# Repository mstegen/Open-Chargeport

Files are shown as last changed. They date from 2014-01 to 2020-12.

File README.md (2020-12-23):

Open ChargePort
===============

What is it?
As the name suggests, it's a transmitter that will open the charge port of a Model S.

When I received my EU spec model S, i charged a few times with the cable Tesla supplies with the car.
The button to open the Charge port door, really is a nice feature.
As there is no such thing on a standard Type 2 charge cable, i now have to open the car door, touch the battery icon, and select open charge port. Not very convenient.

Therefore i wanted to make my own transmitter that opens the chargeport.

Credits to Banahogg who documented his attempts to analyze the RF data here
which helped me finish this project in a few days.

The components needed:

I used a 433 Mhz module connected to a PIC microcontroller. (US model S, requires a 315Mhz module)
Only a few other components are required.

1x PIC12F1822 or PIC10F200 microcontroller 
1x TX-SAW MID/3V
1x Lithium cell, 3V
2x 100nf capacitor
1x 10uf capacitor
1x pushbutton
 
Please note that the PCB layout in /eagle was designed for the PIC10F200 microcontroller.

=======================================================================================

There is now a new version, based on the same chip Tesla uses in it's Charging Cable.

The chip is a Silabs Si4010, only one external component (capacitor) is required.
I converted the Tesla specific bitstream for use with this microcontroller. 
As Silabs also provided a PCB layout file for 5 buttons, but only one button is needed, these files were modified.
The PCB layout fit's the Polycase FB-20 keyfob housing.

All files for this version can be found in the /Si4010 folder.

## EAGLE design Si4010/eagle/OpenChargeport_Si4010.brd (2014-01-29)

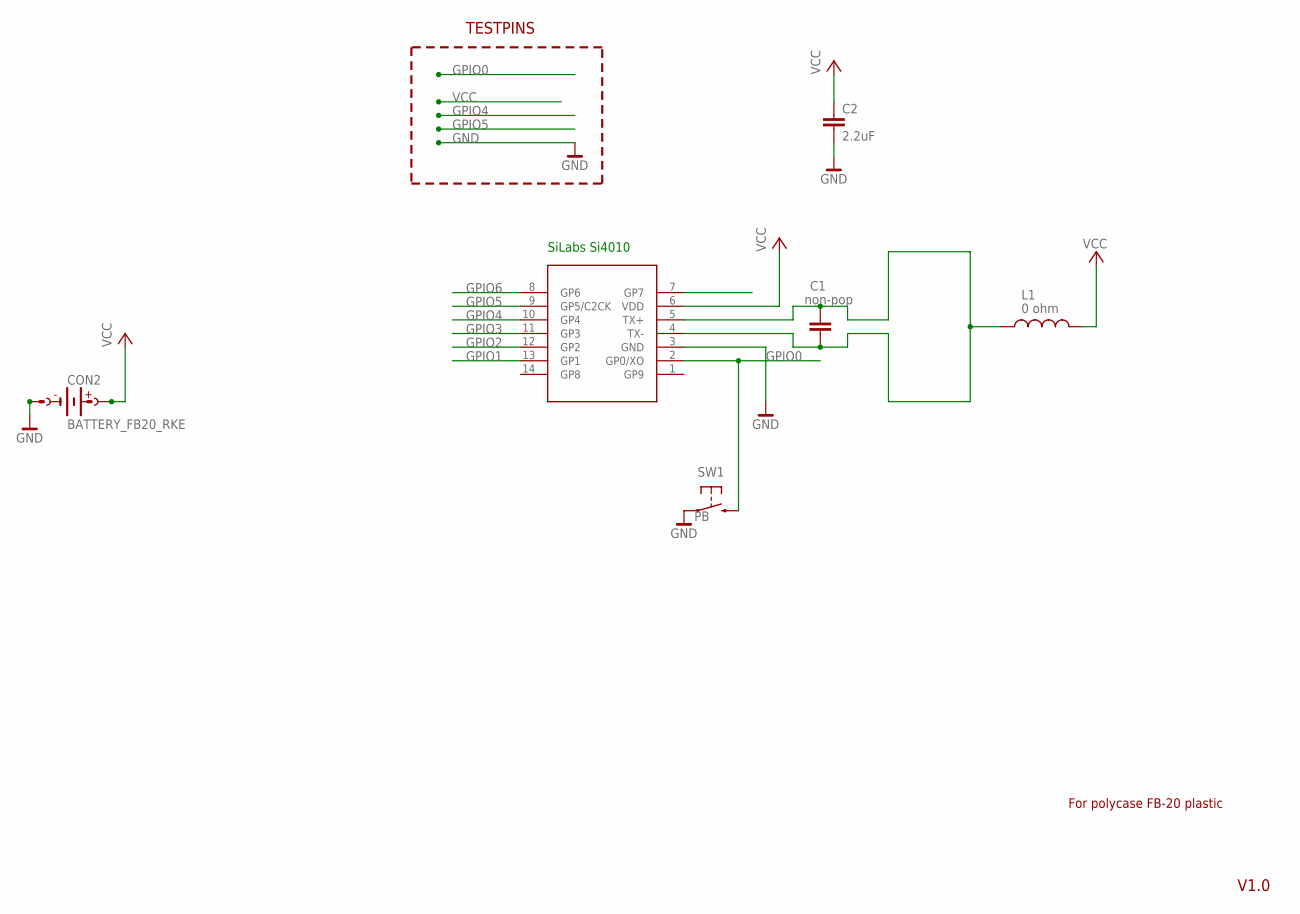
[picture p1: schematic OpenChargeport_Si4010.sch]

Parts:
C1: non-pop; C0603K
C2: 2.2uF; C0805K
CON2: BATTERY_FB20_RKE; BATTERY_HOLDER_CR2032F_RKE_FB20
IC1: SI4010; SOIC-14
L1: 0 ohm; L0402
SW1: PB; PUSHB_PILL

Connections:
ANT: C1.1, C1.2, IC1.4 (TX-), IC1.5 (TX+), L1.1
GND: C2.2, CON2.MINUS (NEG), CON2.MINUS1 (NEG1), IC1.3 (GND), SW1.P$1 (1)
GPIO0: IC1.2 (GP0/XO), SW1.P$2 (2)
GPIO1: IC1.13 (GP1)
GPIO2: IC1.12 (GP2)
GPIO3: IC1.11 (GP3)
GPIO4: IC1.10 (GP4)
GPIO5: IC1.9 (GP5/C2CK)
GPIO6: IC1.8 (GP6)
VCC: C2.1, CON2.PLUS1 (POS), CON2.PLUS2 (POS1), IC1.6 (VDD), L1.2

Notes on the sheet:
TESTPINS
For polycase FB-20 plastic
V1.0
SiLabs Si4010

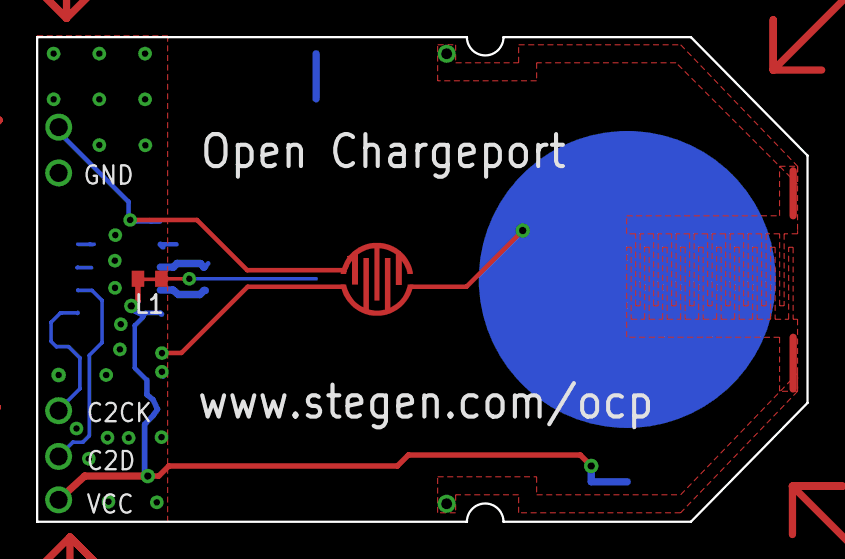
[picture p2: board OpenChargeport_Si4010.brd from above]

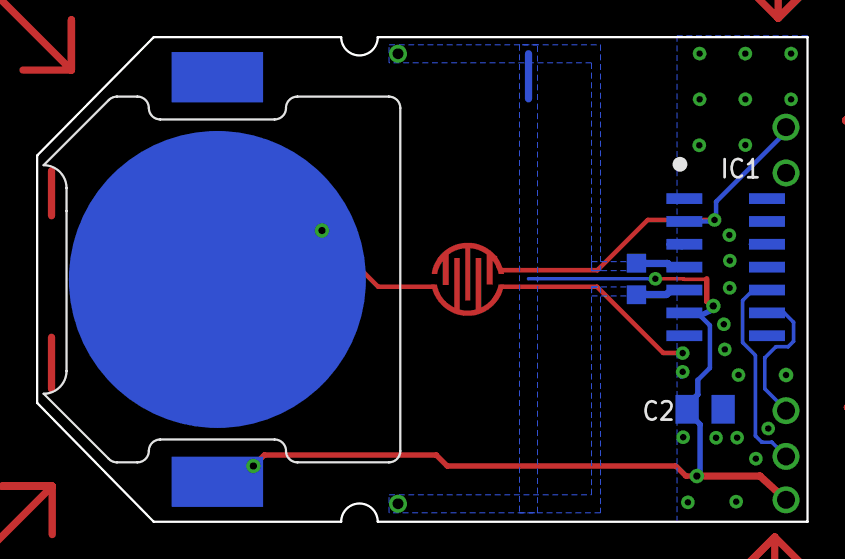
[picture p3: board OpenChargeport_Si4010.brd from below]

Board: 2 copper layers, 42.8 x 26.9 mm, 6 parts (4 on the bottom side), 4 nets.

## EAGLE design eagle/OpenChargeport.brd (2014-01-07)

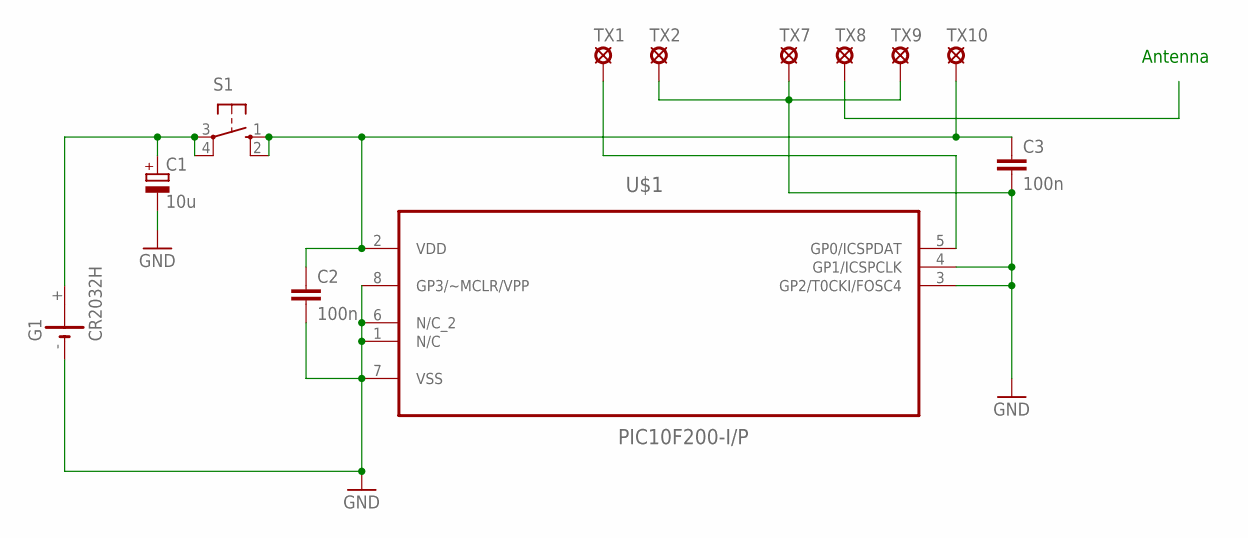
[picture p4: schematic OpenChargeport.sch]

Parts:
C1: 10u; E2,5-5
C2, C3: 100n; C025-025X050
G1: CR2032H
S1: 10-XX; B3F-10XX
TX1, TX2, TX7, TX8, TX9, TX10: LSP10
U$1: PIC10F200-I/P; DIP254P762X533-8

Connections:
GND: C1.-, C2.2, C3.2, G1.-, TX2.MP, TX7.MP, TX9.MP, U$1.1 (N/C), U$1.3 (GP2/T0CKI/FOSC4), U$1.4 (GP1/ICSPCLK), U$1.6 (N/C_2), U$1.7 (VSS), U$1.8 (GP3/~MCLR/VPP)
unnamed: C1.+, G1.+, S1.3, S1.4 (P1)
unnamed: C2.1, C3.1, S1.1 (S), S1.2 (S1), TX10.MP, U$1.2 (VDD)
unnamed: TX1.MP, U$1.5 (GP0/ICSPDAT)

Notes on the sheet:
Antenna

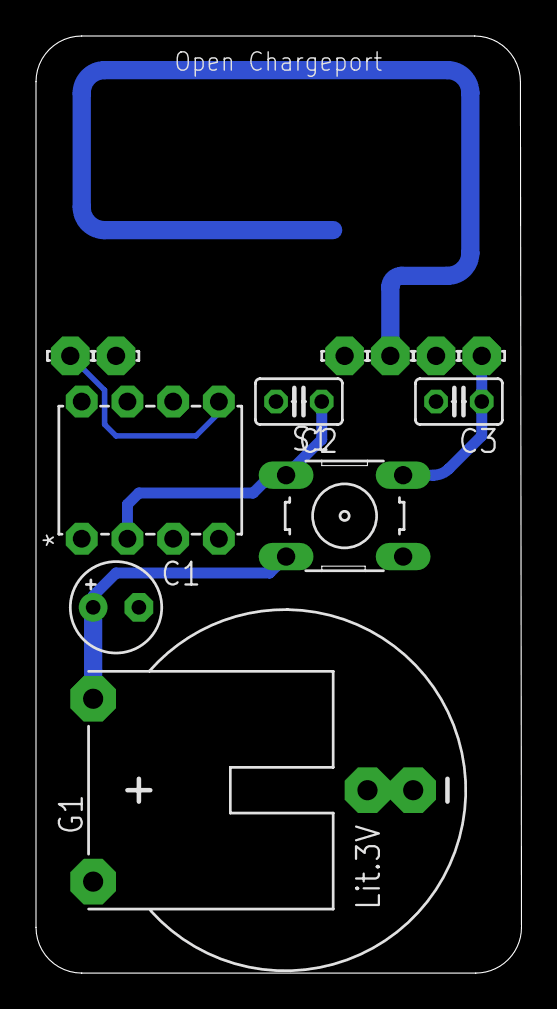
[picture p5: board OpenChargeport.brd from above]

Board: 2 copper layers, 27.0 x 52.1 mm, 12 parts (0 on the bottom side), 4 nets.

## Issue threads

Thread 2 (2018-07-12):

how to burn the files to SI4010?

fenrei, 2018-07-12:
inside source code folder of the  Si4010 folder, there is no HEX file to use, only a .c and .h file, please tell me how can i use with these 2 files, thanks!

mstegen, 2018-07-12:
It's been a while, but you'll need to install Silicon Laboratories wireless development suite, and install the KEIL compiler.
Then also install the example files for the SI4010, see here:
https://www.silabs.com/documents/public/application-notes/AN690.pdf
https://www.silabs.com/documents/public/user-guides/Si4010-DK.pdf

It helps if you own one of the dev kit's as the software is included.
I bought the 4010-DKKF-434 kit, but i noticed it has been replaced by (i think) the 4010-KFOBDEV-434.

Overwrite the installed example (keyfob_demo) with the two files from this repository.
You should then be able to compile the keyfob_demo example, generating the Open Chargeport hexfile.

Be careful, as you can only burn the Si4010 IC's once!, (you can however upload the code to RAM and develop from there)

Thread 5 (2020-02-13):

Does the PIC and Si4010 code generate exactly the same signal?

nicholas-gh, 2020-02-13:
I've determined that https://github.com/mstegen/Open-Chargeport/blob/4fdffded66910fe04250e5dc19f3d89ede9bd17c/Si4010/source/keyfob_demo_main.c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 is the same data as https://teslamotorsclub.com/tmc/posts/2383825/ - after I spotted the [note about LSB](https://github.com/mstegen/Open-Chargeport/blob/4fdffded66910fe04250e5dc19f3d89ede9bd17c/Si4010/source/keyfob_demo_main.c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). The Si4010 code is 'ready to send', so manchester encoding, preamble, message-repeats markers are all already in it; and since the 'message-repeats' marker (100?) isn't a full byte I see how the repeated data actually doesn't look repeated in the Si4010 code.

The data at https://github.com/mstegen/Open-Chargeport/blob/4fdffded66910fe04250e5dc19f3d89ede9bd17c/sourcecode/OpenChargeport_10F200.asm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 is almost the same; but the last few bytes of the repeated message seems to differ.

I think the PIC code generates either

```
010101100101100110010110011001100110011001011010011010010110101001010110100110100110010101011010 100101
```
or potentially (if I'm confused how (MC_TX3)[https://github.com/mstegen/Open-Chargeport/blob/4fdffded66910fe04250e5dc19f3d89ede9bd17c/sourcecode/OpenChargeport_10F200.asm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] works)
```
010101100101100110010110011001100110011001011010011010010110101001010110100110100110010101011010 100
```

and the Si4010 and 'rpitx' examples generate

```
0101011001011001100101100110011001100110010110100110100101101010010101101001101001100101010110100101 100
```

I assume all three of these examples work, and the Tesla port doesn't notice the small variation?

If it works (and I assume it must do since it's here), then the PIC code has the most concise representation of the Tesla button code I've come across so far.

nicholas-gh, 2020-02-13:
Here's my python playaround  to try compare the three examples:
```python
#!/usr/bin/python

# sources
# https://teslamotorsclub.com/tmc/posts/2383825/
# https://github.com/mstegen/Open-Chargeport/blob/master/Si4010/source/keyfob_demo_main.c

thenoone_preamble = "111111111111"
thenoone_data = "00010010100101010101001101100111000110110100001100"
thenoone_rec_split = "100" # not manchester?

Si4010 = [0x55, 0x55, 0x55, 0x51, 0xd3, 0x4c, 0x33, 0x33, 0xd3, 0xb2, 0xb4, 0x52, 0xcb, 0x32, 0xd5, 0xd2, 0xA8, 0x69, 0xa6, 0x99, 0x99, 0x69, 0x59, 0x5a, 0xa9, 0x65, 0x99, 0x6a, 0x69, 0xd4, 0x34, 0xd3, 0xcc, 0xcc, 0xb4, 0x2c, 0xad, 0xd4, 0xb2, 0x4c, 0xb5, 0x34]

pic_preamble = "10"*13 + "0" # 0 is an extra 400us delay after the preamble that's in the code, not in the data
pic = [0x12, 0x95, 0x53, 0x67, 0x1B, 0x43]
pic_3 = 0x20

def manchester(data):
    return "".join(["10" if bit == "1" else "01" for bit in data])
thenoone_symbols = thenoone_rec_split.join([manchester(thenoone_preamble)] + [manchester(thenoone_data)]*3)

print "noone ", [int(thenoone_symbols[b:b+8][::-1], 2) for b in range(0, len(thenoone_symbols), 8)]
print "Si4010", Si4010

pic_symbols = pic_preamble + ("".join([manchester(format(byte, '08b')) for byte in pic]) + manchester(format(pic_3, '03b')))*3
print "pic   ", [int(pic_symbols[b:b+8][::-1], 2) for b in range(0, len(pic_symbols), 8)]

```

and the output is

```
noone  [85, 85, 85, 81, 211, 76, 51, 51, 211, 178, 180, 82, 203, 50, 213, 210, 168, 105, 166, 153, 153, 105, 89, 90, 169, 101, 153, 106, 105, 212, 52, 211, 204, 204, 180, 44, 173, 212, 178, 76, 181, 20]
Si4010 [85, 85, 85, 81, 211, 76, 51, 51, 211, 178, 180, 82, 203, 50, 213, 210, 168, 105, 166, 153, 153, 105, 89, 90, 169, 101, 153, 106, 105, 212, 52, 211, 204, 204, 180, 44, 173, 212, 178, 76, 181, 52]
pic    [85, 85, 85, 81, 211, 76, 51, 51, 211, 178, 180, 82, 203, 50, 213, 74, 85, 53, 205, 52, 51, 51, 45, 75, 43, 181, 44, 83, 173, 84, 85, 211, 76, 51, 51, 211, 178, 180, 82, 203, 50, 213, 74, 85]
```

So the Si4010 and TheNoOne's code varies only at the very end; but I don't understand the Pic code well enough to see if/why its "3 bit" "frame delimiter" is the same result as the other two.

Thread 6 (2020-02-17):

debug / run

FlexyZ-xx, 2020-02-17:
Hi

I know this project is an old one. I just got the si4010-kfobdev-434 devkit and got all the software running - was a pain to find it all

Anyway from Silabs IDE I can connect to the "4010-DKPB434-BM" and download code, but how do I run the code with out being connected to the toolstick/debugger?

Is it correct that I can only burn/flash ones - also on the "4010-DKPB434-BM"?

I hope you can help me :)

Thanks
Felix

mstegen, 2020-02-17:
For programming i used Si4010_NVM_Burn_CL.exe called by a batch file. I found it programmed the fastest.
Not sure anymore where i got that from. It's in a folder called Si4010_NvmProgUtil
Yes the Si4010 IC's are one time programmable only, but as you noticed you can debug/load the program in RAM to test if everything works.

FlexyZ-xx, 2020-02-17:
Thanks for your reply :) - I tried to change the LED to constantly on, but no LED - there is a red LED with activity when uploading code og multi-step

When I press F5/RUN can I remove 4010-DKPB434-BM from the Toolstick and should it keep running? - it has a battery on the back side. Or do I have to test while connected to my computer?

btw. Will this https://www.telstore.it/en/650201131g.html work for the PIC project?

Felix

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

FlexyZ-xx, 2020-02-17:
Hey

Maybe I did not create the project correct in Silabs IDE. I just added your files and the 4010 include files.

But when I "Build Male/Project" I get a lot of *** WARNING L1: UNRESOLVED EXTERNAL SYMBOL
, so I guess I need to link with a library or?

Thanks again
Felix

FlexyZ-xx, 2020-02-17:
Got a little closer by adding the license to KEIL - tried to replace the .c and .h on the "keyfob_demo_2" example folder, but don't seem to work - does the screendump look correct? - or could you send me your original project, so I get all the options correct?

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

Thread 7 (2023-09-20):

Is code change required if we use Si4010 10-pin variant?

mgsanava, 2023-09-20:
This is not an issue maybe.
I replicated the Si4010 based circuit and dumped the hex code into IC. I'm using 10-pin variant of Si4010.

(Download sample codes from Si4010 page -> duplicated keyfob_demo_2 project -> deleted the actual usr_src files -> added your source files -> compiled successfully -> hex generated -> downloaded hex successfully using Silabs IDE)

Now when I press the switch, I couldn't see any signal on the TXM TPM pins. Attached schematic also.

Do I need to change something in code? All I could see was TXM TPM pin numbers were changed.

I posted this on Tesla club also but was approved yet and this is urgent. Hence posting here again. Any help is appreciated. Thanks.

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

mstegen, 2023-09-21:
I don't think the variant of the IC matters. But please check the sourcecode, if you want to test the code, you can run the program from RAM, to do so you will have to comment out some lines. The chips can be flashed only once, so if you flashed your IC, you will have to unsolder it, and solder in a new one.

Looking at your schematic, C2 should not be 100nf, in my schematic it's unused., as this is the output of the transmitter, the 100nf capacitor will absorb the RF signal.

mgsanava, 2023-09-22:
Thank you for the reply.
> The chips can be flashed only once
I got lost there. I burned the chip 3 times already but it never said download failed.
Every time code was downloaded successfully which I could see in IDE log window. Definitely something is wrong?
I will change the chip anyway.

I checked the source code but I do not see anything related to RAM. I will dig deeper and it would be great if you can provide any leads on this topic.

I removed the C2 as suggested.

mgsanava, 2023-09-25:
@mstegen
Can you please comment?

mstegen, 2023-09-26:
It has been 10 years ago since i last looked at the code, i don't have the IDE installed anymore on my PC, but i remembered that you could run the software from RAM, and not program it to flash.

Please search the documentation for this. Also this is the line that you need to comment out if you want to debug it:

https://github.com/mstegen/Open-Chargeport/blob/331fc6fb402cc5cf49b122092cd722234c0e0293/Si4010/source/keyfob_demo_main.c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

mgsanava, 2023-09-26:
I'll look into documentation further.
Thanks for the help!

mgsanava, 2023-09-29:
This is just a note about Si4010 Flashing for future readers including myself:

_**Courtesy: Silabs Community**_
Si4010 stores the user code in OTP memory (called NVM in documentation). Programming NVM requires 6.5V programming voltage and Silabs NVM programming utility SW, cannot be done from IDE. During boot, user code is loaded from NVM to RAM, and runs from RAM.

IDE loads the code directly to RAM for debugging, that's why you can do it multiple times.

RAM content is lost in shutdown state.

No code change needed for 10-pin variant, if you do not use the nonexistent GPIOs.

See further details in [Si4010 datasheet](https://www.silabs.com/documents/public/data-sheets/Si4010.pdf) and [AN370: Si4010 Software Programming Guide](https://www.silabs.com/documents/public/application-notes/AN370.pdf)

mgsanava, 2023-10-11:
Hi @mstegen
just wanted a help from you. do you still have the waveforms data on how they look on an oscilloscope?
i tried the setup and ended up with some signal but i'm quite sure they are not correct.
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

mstegen, 2023-10-12:
No i do not have the waveform, but you can record it yourself with a 433 mhz receiver, and a tesla wall connector plug.
Please note that in the USA, the frequency is not 433 Mhz but 315Mhz if i remember correctly. That might be the reason it does not work for you.
You can set the TX frequency in the sourcecode. The antenna is not tuned for 433 Mhz, but it should still work on 315Mhz. (i verified that at the time)

Closed 2023-09-26.

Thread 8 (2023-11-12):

What is the purpose of L1?

markusdd, 2023-11-12:
L1 (which is only a 0 Ohm resistor as it seems) apparently supplies VCC to the antenna and is populated: why?

Can you maybe point to the datasheet where this is used? Or is this supposed to be a Ferrite Bead?

Also: wouldn't it make sense to try to fit it on the bottom layer as well so the PCB becomes easier to manufacture? Because currently it would require 2-sided assembly.

mstegen, 2023-11-13:
It was a hack to connect the two busses (VCC and ANT) together

markusdd, 2023-11-13:
I thought so.
I imported the board files into KiCAD and noticed that otherwise DRC will go crazy on you^^

Is there a reason why the whole antenna is put under VDD? Is that recommended by SiLabs?

mstegen, 2023-11-13:
I used their reference PCB design, and deleted the other 4 buttons, but kept everything else the same.

markusdd, 2023-11-13:
Interesting stuff, need to read up on why they do that, never have seen that before.

Thanks for your insights!

Closed 2023-11-13.

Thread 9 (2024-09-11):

Is Hex file available for Si4010 version (with 315MHz frequency support)?

mgsanava, 2024-09-11:
Hi @mstegen

I was able to compile the code available in your repo but not sure if it is working or not because I was not able to identify any output signal after flashing the code (tried on both RAM and OTP memories). I am checking in an oscilloscope, and I don't have the facilities to test with an actual car because I'm in a different country.

I could see [here](https://github.com/mstegen/Open-Chargeport/blob/331fc6fb402cc5cf49b122092cd722234c0e0293/Si4010/source/keyfob_demo.h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) that frequency you assigned is 433MHz for EU region. For which value assigned was _433920000_. Is there any specific reason why it is not _433000000_? Can I just use _315000000_ for 315MHz?

My schematic and board are completely identical to the one in the repo. Is it enough to just modify the [`fOperatingFrequency`](https://github.com/mstegen/OpenChargeport/blob/331fc6fb402cc5cf49b122092cd722234c0e0293/Si4010/source/keyfob_demo.h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) and flash? Or do I need to comment out any lines in the code?

Schematic:
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
Please let me know if PCB layout is required.

Your help is highly appreciated. Thanks!

mgsanava, 2024-09-12:
PCB:

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

mstegen, 2024-09-12:
The reason for the 433,920 Mhz frequency is because that exact frequency is used on all transmitters in the EU, it's free to use.
In the USA it's 315 Mhz, not sure about the exact frequency.
I once sent a OpenChargeport key fob to the USA to test, and it worked fine, even with the default antenna design.

You can test your transmitter by using a 315Mhz receiver module connected to your oscilloscope.

mgsanava, 2024-09-13:
Thanks @mstegen
My receiver is: XY-MK-5V (315MHz) version for testing where I probe DATA pin for signal capture.
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

I am not sure if DATA pin signal frequency is downscaled or not because I have an oscilloscope of 100MHz and 1Gs read specification. As far as I know, frequencies higher than 100MHz bandwidth will not be captured by scope correctly.
I did not find further information about this DATA pin, but I see people using Arduinos to interpret the signal on DATA pin using serial monitor.

Is there a better way to interpret the receiving signal?

mstegen, 2024-09-13:
If you follow the original thread on teslamotorclubforum you can see what you should expect to see on your scope screen.
The bandwidth of your scope is fine.
As this project was done a long time ago i don't remember any more details, sorry.

mgsanava, 2024-09-17:
It's ok, thanks.
One last question - if I want to try this out in another microcontroller, I just need to relay the exact 42-byte data sequence in the [vPacketAssemble()](https://github.com/mstegen/Open-Chargeport/blob/331fc6fb402cc5cf49b122092cd722234c0e0293/Si4010/source/keyfob_demo_main.c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) function, right?

mstegen, 2024-09-17:
No, that depends on how the data is transmitted, as you can see in the pic code here:
https://github.com/mstegen/Open-Chargeport/blob/master/sourcecode/OpenChargeport.asm#L203

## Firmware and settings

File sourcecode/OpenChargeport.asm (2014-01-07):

;******************************************************************************
;   Open Chargeport                         						          *
;   For use with Tesla Model S                                                *
;******************************************************************************
;                                                                             *
;    Filename:     OpenChargeport.asm                                         *
;    Date:         4-9-13                                                    *
;    File Version: 1.00                                                       *
;                                                                             *
;    Author:       M. Stegen                                                  *
;    Company:      Stegen Electronics                                         *
;                                                                             *
;                                                                             *
;******************************************************************************
;                                                                             *
;    *
;    *
;	 
;																			  *
;******************************************************************************
;                                                                             *
;    Revision History:                                                        *
;	 1.00 		initial release												  *
;																			  *
;******************************************************************************
;
;
;
;	       +----_----+
;	 VDD --| 1     8 |-- GND 
;	 NC  --| 2     7 |-- TX Out
;	 NC  --| 3     6 |-- NC
;	 NC  --| 4     5 |-- NC
;	       +---------+
;
;
;*****************************************************************************



	list		p=12F1822      ; list directive to define processor
	#include	<p12F1822.inc> ; processor specific variable definitions

;------------------------------------------------------------------------------
;
; CONFIGURATION WORD SETUP
;
; The 'CONFIG' directive is used to embed the configuration word within the 
; .asm file. The lables following the directive are located in the respective 
; .inc file.  See the data sheet for additional information on configuration 
; word settings.
;
;------------------------------------------------------------------------------    

    __CONFIG _CONFIG1, _FOSC_INTOSC & _WDTE_OFF & _PWRTE_ON & _MCLRE_OFF & _CP_ON & _CPD_ON& _BOREN_OFF & _CLKOUTEN_OFF & _IESO_OFF & _FCMEN_OFF
    __CONFIG _CONFIG2, _WRT_OFF & _PLLEN_OFF & _STVREN_OFF & _BORV_19 & _LVP_OFF



;------------------------------------------------------------------------------
; VARIABLE DEFINITIONS
;
; Available Data Memory divided into Bank 0-15.  Each Bank may contain 
; Special Function Registers, General Purpose Registers, and Access RAM 
;
;------------------------------------------------------------------------------

; RAM-Variables


Mcount      EQU    	0x71
Count		EQU		0x72
Serdata		EQU		0x73

TX			EQU		0		; pin 7	TX output

;------------------------------------------------------------------------------
; RESET VECTOR
;------------------------------------------------------------------------------

    ORG     0x0000            ; processor reset vector

	goto    INIT              ; When using debug header, first inst.
                              ; may be passed over by ICD2.  

;-------------------------------------------------------------------------
; Send 3 bits (in W) (MSB)

MC_TX3
		movwf	Serdata
		MOVLW 	3
		MOVWF 	Count			; 3 BITS TO send
		goto	MC_TXLOOP

;-------------------------------------------------------------------------
; Send one byte (in W)
MC_TX
		movwf	Serdata
		MOVLW 	8
		MOVWF 	Count			; 8 BITS TO send
		
MC_TXLOOP
		CLRF	TMR0

		BTFSS	Serdata,7		; check MSB
		BCF		PORTA,TX		; Signal LOW 	=> 01
		BTFSC	Serdata,7		; check MSB
		BSF		PORTA,TX		; Signal HIGH 	=> 10
MC1_400us
		MOVF	TMR0,W
		XORLW	.25				; 0.000016 * 25= 400 uS
		BTFSS	STATUS,Z
		GOTO	MC1_400us

		BTFSC	Serdata,7		; check MSB
		BCF		PORTA,TX		; Signal LOW	=> 01
		BTFSS	Serdata,7		; check MSB
		BSF		PORTA,TX		; Signal HIGH	=> 10

MC2_400us
		MOVF	TMR0,W
		XORLW	.50				; 0.000016 * 50= 800 uS total
		BTFSS	STATUS,Z
		GOTO	MC2_400us

		RLF		Serdata,F
		decfsz	Count,F
		goto	MC_TXLOOP	
		return


;------------------------------------------------------------------------------
;
SEND_SYNC
		BANKSEL PORTA

		movlw	.13
		movwf	Count
sync_loop
		CLRF	TMR0
		BSF		PORTA,TX		; High
high_400
		MOVF	TMR0,W
		XORLW	.25				; 0.000016 * 25= 400us
		BTFSS	STATUS,Z
		GOTO	high_400

		BCF		PORTA,TX		; Low
low_400
		MOVF	TMR0,W
		XORLW	.50				; 0.000016 * 50= 800us
		BTFSS	STATUS,Z
		GOTO	low_400
		decfsz	Count,F			; repeat
		goto	sync_loop
		return	

;------------------------------------------------------------------------------
;
delay400us
		CLRF	TMR0
dly400us
		MOVF	TMR0,W
		XORLW	.25				; 0.000016 * 25= 400 uS
		BTFSS	STATUS,Z
		GOTO	dly400us
		return

delay25ms
		movlw	.62
		movwf	Count
dly25ms		
		call	delay400us
		decfsz	Count,F
		goto	dly25ms
		return
	

;------------------------------------------------------------------------------
; INITIALIZE all REGISTERS
;------------------------------------------------------------------------------

INIT	
		BANKSEL OPTION_REG
		movlw	B'11000110'
		movwf	OPTION_REG		; prescaler 1:128, Weak pull-ups disabled
								; same bank
		movlw	b'11110000'		
		movwf	OSCCON			; setup 32Mhz internal oscillator

		BANKSEL PORTA 
		CLRF 	PORTA 			; Init PORTA
		BANKSEL LATA 			; Data Latch
		CLRF 	LATA 
		BANKSEL ANSELA 
		CLRF 	ANSELA 			; digital I/O
		BANKSEL TRISA 		
		MOVLW 	B'00111110' 	; set pin 7 as output (TX)
		MOVWF 	TRISA 			; the rest as input



MAIN
		call	SEND_SYNC		; send 13 sync bits
		movlw	.3
		movwf	Mcount
Mloop
		call	delay400us
		movlw	0x12			
		call	MC_TX
		movlw	0x95			
		call	MC_TX
		movlw	0x53			
		call	MC_TX
		movlw	0x67			
		call	MC_TX
		movlw	0x1B			
		call	MC_TX
		movlw	0x43			
		call	MC_TX
		movlw	0x20			
		call	MC_TX3
		decfsz	Mcount,F
		goto	Mloop

		call	delay25ms

		goto 	MAIN			; loop forever
    


    END

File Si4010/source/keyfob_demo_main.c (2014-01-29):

/*------------------------------------------------------------------------------
 *                          Silicon Laboratories, Inc.
 *                           http://www.silabs.com
 *                               Copyright 2010
 *------------------------------------------------------------------------------
 *
 *    FILE:       keyfob_demo_main.c
 *    TARGET:     Si4010
 *    TOOLCHAIN:  Keil
 *    RELEASE:    1.1 ; ROM version 02.00
 *    AUTHOR:     Miklos Lukacs, 
 *                modified by Michael Stegen for use as Open Chargeport
 *    DATE:       October 07, 2013
 *
 *------------------------------------------------------------------------------
 *
 *    DESCRIPTION:
 *      This file contains the main function for the Keil toolchain
 *      sample keyfob_demo project.
 *
 *      BL51 linker directives for building this application:
 *
 *      BL51: PL(68) PW(78) IXREF RS(256)
 *            CODE (0x0-0x08FF)
 *            DATA (0x40)
 *            IDATA (0x80)
 *            XDATA (0x0900-0x107F)
 *            STACK (?STACK(0x8A))
 *
 *------------------------------------------------------------------------------
 *
 *    INCLUDES:
 */
#include <stdlib.h>
#include "si4010.h"
#include "si4010_api_rom.h"

/* Demo header */
#include "keyfob_demo.h"

/*------------------------------------------------------------------------------
 *
 *    FUNCTION DESCRIPTION:
 *      This function tunes the si4010 for transmission and transmits frames.
 *      It consists of two fundamental phases, setup and the transmission loop.
 *
 *      Setup Phase:
 *        The Setup Phase calls all setup function for the need API modules.
 *        These functions are to be called once per boot of the chip.
 *          vSys_Setup
 *          vPa_Setup
 *          vOds_Setup
 *          vStl_EncodeSetup
 *          vFCast_Setup
 *
 *      Transmission Loop Phase:
 *        The Transmission Loop Phase is a loop which transmits the proper frame
 *		  once a button is pushed. Frequency casting, FSK adjustment
 *        and PA tuning are all performed between each transmission.
 *
 *------------------------------------------------------------------------------
 */
void main(void)
{
/*------------------------------------------------------------------------------
 *    SETUP PHASE
 *------------------------------------------------------------------------------
 */
//Set DMD interrupt to high priority,
// any other interrupts have to stay low priority
  PDMD=1;

// Parameters Initialization. 
  vAppInitial();


// Call the system setup. This just for initialization.
// Argument of 1 just configures the SYS module such that the
// bandgap can be turned off if needed.
  vSys_Setup( 1 );

// Setup the bandgap for working with the temperature sensor here 
  vSys_BandGapLdo( 1 );
 
// Setup the BSR 
  vBsr_Setup( &rBsrSetup );

// Setup the RTC to tick every 5ms and clear it. Keep it disabled. 
  RTC_CTRL = (0x07 << B_RTC_DIV) | M_RTC_CLR;

// Enable the RTC 
  RTC_CTRL |= M_RTC_ENA;

// Enable the RTC interrupt and global interrupt enable 
  ERTC = 1;
  EA = 1;

// Setup the PA 
  vPa_Setup( &rPaSetup );

// ODS setup 
  vOds_Setup( &rOdsSetup );

// Setup the STL encoding to NoneNrz code. we
// leave the pointer at NULL. 
//  vStl_EncodeSetup( bEnc_Manchester_c, NULL );
  vStl_EncodeSetup(   bEnc_NoneNrz_c, NULL );


// Setup frequency casting .. needed to be called once per boot 
  vFCast_Setup();



/*------------------------------------------------------------------------------
 *    TRANSMISSION LOOP PHASE
 *------------------------------------------------------------------------------
 */

 // Application loop, including push button state analyzation and transmission.
  while(1)
  {
    // Buttons analyzation and update task flag. 
    vButtonCheck();

    if (bAp_ButtonState)
    {
      // Set frame size and frame header pointer 
      vPacketAssemble();
	  if (lPayLoad)
	  {
      // Start to transmit
      vRtl_RepeatTxLoop();
      }
    }
    else if( (lSys_GetMasterTime() >> 5) > bMaxWaitForPush_c )
    {
      // Shutdown if timeout, currently after about 1.6s,
      // For debugging with IDE, comment it out since it does not support boot.
      vSys_Shutdown();
    }
  }
}


/*------------------------------------------------------------------------------
 *
 *    FUNCTION DESCRIPTION:
 *      Initialization of Application parameters. 
 *
 *------------------------------------------------------------------------------
 */
 void vAppInitial(void)
{
// Disable the Matrix and Roff modes on GPIO[3:1] 
  PORT_CTRL &= ~(M_PORT_MATRIX | M_PORT_ROFF | M_PORT_STROBE);
  PORT_CTRL |=  M_PORT_STROBE;
  PORT_CTRL &= (~M_PORT_STROBE);

// Turn LED control off 
  GPIO_LED = 0;
// Set LED intensity .. acceptable values are 0 (off) or 1, 2, and 3 
  vSys_LedIntensity( 0 );

  // Initial debouce time. 
  bIsr_DebounceCount = 0;
  // debounce time definition, the unit is defined by the RTC interrupt time
  //(5ms in the demo).It means that the interval between calls to the
  // vBsr_Service() function is 5*8=40ms.
  // BSR parameters initialization 
  rBsrSetup.bButtonMask = 0x1F;	// GPIO0 only
  rBsrSetup.pbPtsReserveHead = abBsrPtsPlaceHolder;
  rBsrSetup.bPtsSize = 10;
  rBsrSetup.bPushQualThresh = 3;

// Setup the PA.
// fAlpha and fBeta has to be set based on antenna configuration.
// Chose a PA level and nominal cap. Both values come from
// the calculation spreadsheet. 
  rPaSetup.fAlpha      = 0.0;
  rPaSetup.fBeta       = 0.3593;
  rPaSetup.bLevel      = 0;
  rPaSetup.wNominalCap = 10;
  rPaSetup.bMaxDrv     = 0;

 // Setup the ODS 
  rOdsSetup.bModulationType = bRke_OokMod_c; // Use OOK 
//  rOdsSetup.bModulationType = bRke_FskMod_c; // Use FSK 
  rOdsSetup.bClkDiv         = 5;
  rOdsSetup.bEdgeRate       = 0;

// Set group width to 7, which means 8 bits/encoded byte to be transmitted.
// The value must match the output width of the data encoding function
// set by the vStl_EncodeSetup() below! 
  rOdsSetup.bGroupWidth     = 7;
// 24MHz / (bClkDiv+1) / 9.6kbps = 417 
  rOdsSetup.wBitRate        = 1600; // 1,25kbps

// Configure the warm up intervals LC: 8, DIV: 4, PA: 4 
  rOdsSetup.bLcWarmInt  = 8;
  rOdsSetup.bDivWarmInt = 5;
  rOdsSetup.bPaWarmInt  = 4;

// Set external crystal oscillator parameters - 10MHz, 12pF 
// currently XO is not used in this example
  rFCast_XoSetup.fXoFreq = 10000000;//12729633;
  rFCast_XoSetup.bLowCap = 1;

  return;
}

/*------------------------------------------------------------------------------
 *
 *    FUNCTION DESCRIPTION:
 *      This function contains the loop which consists of three procedures,
 *      tx setup, tx loop and tx shutdown in the application.
 *      During waiting for repeat transmission, check button state.
 *      Once any new push button is detected, then transmit the new packet 
 *      instead of the current packet.
 *
 *------------------------------------------------------------------------------ 
 */
void vRtl_RepeatTxLoop(void)

{ 

// Repeat packet 8 times for each button packet transmission. 
  bRepeatCount = bRepeatCount_c;


 
  do
  {
    // Setup the bandgap  
    vSys_BandGapLdo( 1 );

    // Save current timestamp for repeat transmission interval checking later. 
    lTimestamp = lSys_GetMasterTime();

    // Run at 433.92 MHz (frequency).Input is in [Hz]. 
	// The function also calculates necessary data to be used by the single Tx loop 
	// main function, vStl_SingleTxLoop(), for fine frequency correction during TX
    vFCast_Tune( fOperatingFrequency );

    // bFskDeviation comes from the calculation spreadsheet.
   // vFCast_FskAdj( bFskDeviation ); 	

    // Now wait until there is a temperature value  
    while ( 0 == bDmdTs_GetSamplesTaken() ){}

    // Tune the PA with the current temperature as an argument 
    vPa_Tune( iDmdTs_GetLatestTemp());

    // Sets up the temperature sensor and demodulator,
    // enable ODS before entering the single tx loop. 
    vStl_PreLoop();

    // Then assign the first address of the frame buffer to
    // the packet pointer used for transmission. 
    pbRke_FrameHead = abButtonFrame;

    // call the single tx loop function 
    vStl_SingleTxLoop(pbRke_FrameHead,
                      bFrameSize_c);

    // Disable the temperature sensor and ODS
    vStl_PostLoop();

    // Disable Bandgap and LDO 
     vSys_BandGapLdo(0);


     //turn LED on
	 GPIO_LED = 1; 
	       
    // Wait repeat interval. 
    while ( (lSys_GetMasterTime() - lTimestamp) < wRepeatInterval );

  	//turn LED off
 	GPIO_LED = 0;
  }while(--bRepeatCount);

  // After repeat transmission, clear all tasks flag. 
  bAp_ButtonState = 0;

  // Clear time value for next button push detecting. 
  vSys_SetMasterTime(0);
  return;
}
 
/*
 *------------------------------------------------------------------------------
 *
 *    FUNCTION DESCRIPTION:
 *      Update the master time by 5, every time this isr is run, and call the 
 * 		Button Service Routine
 *
 */

void isr_rtc (void) interrupt INTERRUPT_RTC using 1

{ 

  // clear the RTC_INT 
  RTC_CTRL &= ~M_RTC_INT;
  vSys_IncMasterTime(5); 
  bIsr_DebounceCount ++;
  if ((bIsr_DebounceCount % bDebounceInterval_c) == 0)
  {
    vBsr_Service();
  }
  return;
}

/*
 *------------------------------------------------------------------------------
 *
 *    FUNCTION DESCRIPTION:
 *      Update bAp_ButtonState which indicates what to be transmitted.
 *      Check the elements on PTS (push tracking strcture) to see if any GPIO
 *      has been pressed or released.
 *      If any new pressed button has detected, the corresponding flag will be set and
 *      the associated information will be transmitted in the application loop procedure.
 *
 *------------------------------------------------------------------------------ 
 */
void vButtonCheck( void)
{ 
  ERTC = 0;		// Disable RTC interrupt, otherwise button state might be corrupted.
  bAp_ButtonState = 0;
  if (bBsr_GetPtsItemCnt())
  {							// GPIO status have been changed.
							// Some buttons may have been pressed or released. 
	bAp_ButtonState = wBsr_Pop() & 0xFF;
	if (bPrevBtn)
	{
	bPrevBtn = bAp_ButtonState;
	bAp_ButtonState = 0;
	}
	else
	{
	bPrevBtn = bAp_ButtonState;
	}
  }
  ERTC = 1;                 // Enable RTC interrupt
  return;
}

/*------------------------------------------------------------------------------
 *
 *    FUNCTION DESCRIPTION:
 *      This function is used to update the packet for transmission,
 *      it is called after vAp_AnalyzeButton(), according to the
 *      the result of buttons analyzation to decide which packet
 *      to be transmited.
 *
 *------------------------------------------------------------------------------ 
 */
void vPacketAssemble ( void)
{
  /* Normal packet transmission mode, send the associated packet
   *
   * Note that Output Data Serializer (ODS) is in little endian fashion,
   * bit 0 first and inverted. So each byte of the packet data should be
   * converted properly before writing into frame buffer.
   */

 /*   switch (bAp_ButtonState)
    {
    case bButton1_c:
      lPayLoad = lFramePayLoad1_c;
      break;
    case bButton2_c:
      lPayLoad = lFramePayLoad2_c;
      break;
    case bButton3_c:
      lPayLoad = lFramePayLoad3_c;
      break;
    case bButton4_c:
      lPayLoad = lFramePayLoad4_c;
      break;
    case bButton5_c:
      lPayLoad = lFramePayLoad5_c;
      break;
    default:
      lPayLoad = 0;
      break;
    }
*/
    // Fill frame buffer with the corresponding button data.
    abButtonFrame[0] = 0x55;
    abButtonFrame[1] = 0x55;
    abButtonFrame[2] = 0x55;

    abButtonFrame[3] = 0x51;	// Tesla specific data
    abButtonFrame[4] = 0xd3;
    abButtonFrame[5] = 0x4c;
    abButtonFrame[6] = 0x33;
    abButtonFrame[7] = 0x33;
    abButtonFrame[8] = 0xd3;
    abButtonFrame[9] = 0xb2;
    abButtonFrame[10] = 0xb4;
    abButtonFrame[11] = 0x52;
    abButtonFrame[12] = 0xcb;
    abButtonFrame[13] = 0x32;
    abButtonFrame[14] = 0xd5;
    abButtonFrame[15] = 0xd2;

	abButtonFrame[16] = 0xA8;
	abButtonFrame[17] = 0x69;
	abButtonFrame[18] = 0xa6;
	abButtonFrame[19] = 0x99;
	abButtonFrame[20] = 0x99;
	abButtonFrame[21] = 0x69;
	abButtonFrame[22] = 0x59;
	abButtonFrame[23] = 0x5a;
	abButtonFrame[24] = 0xa9;
	abButtonFrame[25] = 0x65;
	abButtonFrame[26] = 0x99;
	abButtonFrame[27] = 0x6a;
	abButtonFrame[28] = 0x69;

	abButtonFrame[29] = 0xd4;
	abButtonFrame[30] = 0x34;
	abButtonFrame[31] = 0xd3;
	abButtonFrame[32] = 0xcc;
	abButtonFrame[33] = 0xcc;
	abButtonFrame[34] = 0xb4;
	abButtonFrame[35] = 0x2c;
	abButtonFrame[36] = 0xad;
	abButtonFrame[37] = 0xd4;
	abButtonFrame[38] = 0xb2;
	abButtonFrame[39] = 0x4c;
	abButtonFrame[40] = 0xb5;
	abButtonFrame[41] = 0x34;	




	return;
}

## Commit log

2014-01-29 Added Si4010 source + PCB layout
    [OpenChargeport_SI4010.brd, OpenChargeport_SI4010.sch, OpenChargeport_Si4010.brd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]
2014-01-29 removed double files
    [OpenChargeport_SI4010.brd, OpenChargeport_SI4010.sch]
